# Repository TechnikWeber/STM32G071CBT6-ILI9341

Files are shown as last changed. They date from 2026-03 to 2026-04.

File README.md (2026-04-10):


</br>





Known issues:
ILI9341 Footprint doesnt match!



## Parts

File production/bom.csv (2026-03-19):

Designator | Footprint | Quantity | Value | LCSC Part #
C1, C2 | 0805 | 2 | 6.8pF
C10, C11, C5, C6, C8 | 0805 | 5 | 100nF
C12, C13 | CP_Radial_D6.3mm_P2.50mm | 2 | 10uF
C3, C4 | 0805 | 2 | 22pF
C7 | 0805 | 1 | 4.7uF
D2 | 0805 | 1 | Red
DS1 | ILI9341 | 1 | ILI9341
IC1 | QFP50P900X900X160-48N | 1 | STM32G071CBT6 | C432212
J4, J5 | PinHeader_1x03_P2.54mm_Vertical | 2 | Conn_01x03
R1 | 0805 | 1 | 150R
SW1 | SW_SPST_PTS645Sx43SMTR92 | 1 | RESET | C7470157
SW2 | SW_SPST_PTS645Sx43SMTR92 | 1 | BOOT0 | C7470157
SW3 | SW_SPST_PTS645Sx43SMTR92 | 1 | USER | C7470157
U1 | SOT-223-3_TabPin2 | 1 | AMS1117-3.3
Y1 | Crystal_SMD_3215-2Pin_3.2x1.5mm | 1 | 32.768kHz 6pF | C95361
Y2 | Crystal_SMD_HC49-SD | 1 | 16MHz 16pF | C19631568

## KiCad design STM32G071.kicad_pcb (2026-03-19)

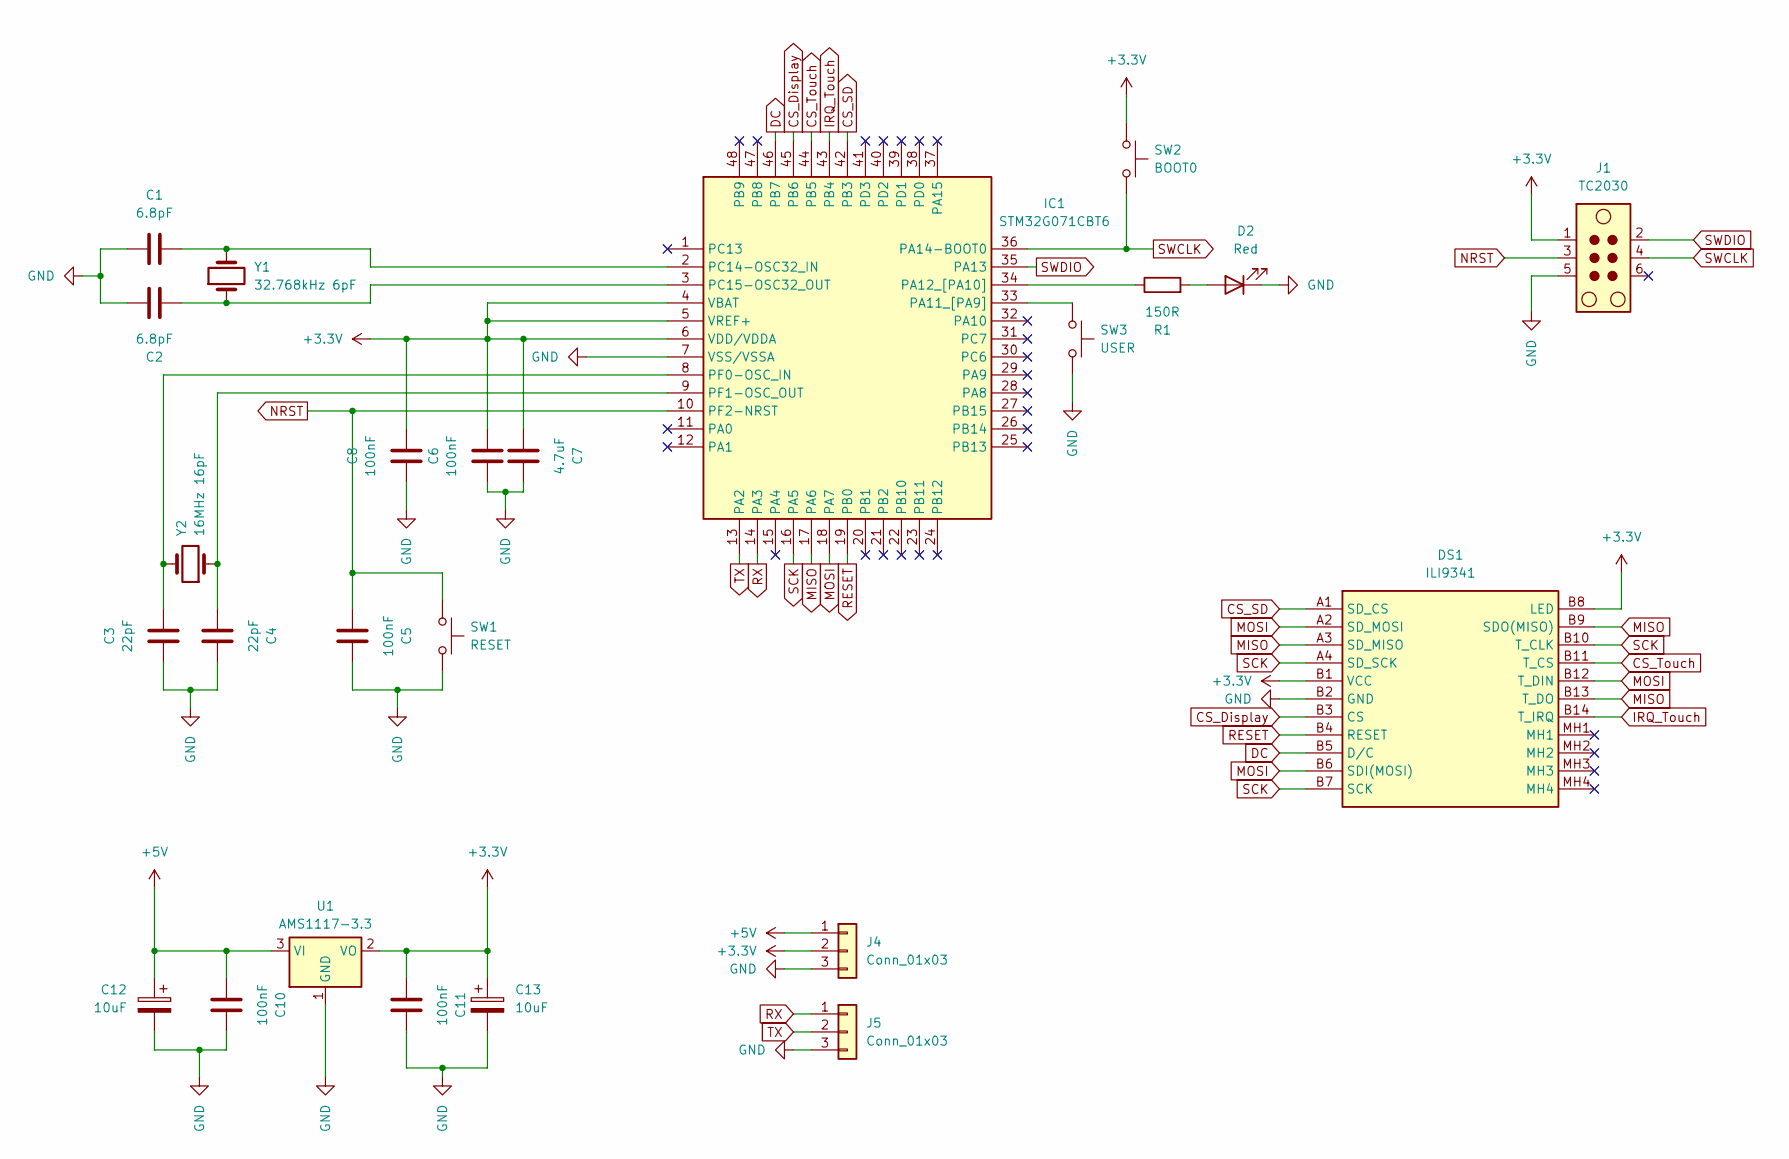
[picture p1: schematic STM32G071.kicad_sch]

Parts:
C1, C2: 6.8pF; C_0805_2012Metric; JLC C1832
C3: 22pF; C_0805_2012Metric; JLC C1804
C4: 22pF; C_0805_2012Metric
C5, C6, C8, C10, C11: 100nF; C_0805_2012Metric; JLC C49678
C7: 4.7uF; C_0805_2012Metric; JLC C1779
C12, C13: 10uF; CP_Radial_D6.3mm_P2.50mm
D2: Red; LED_0805_2012Metric
DS1: ILI9341; Manufacturer_Part_Number ILI9341
IC1: STM32G071CBT6; QFP50P900X900X160-48N; Manufacturer_Part_Number STM32G071CBT6; Mouser Part Number 511-STM32G071CBT6
J1: TC2030; Tag-Connect_TC2030-IDC-FP_2x03_P1.27mm_Vertical
J4, J5: Conn_01x03; PinHeader_1x03_P2.54mm_Vertical
R1: 150R; R_0805_2012Metric; JLC C17471
SW1: RESET; SW_SPST_PTS645Sx43SMTR92; JLC C7470157
SW2: BOOT0; SW_SPST_PTS645Sx43SMTR92; JLC C7470157
SW3: USER; SW_SPST_PTS645Sx43SMTR92; JLC C7470157
U1: AMS1117-3.3; SOT-223-3_TabPin2
Y1: 32.768kHz 6pF; Crystal_SMD_3215-2Pin_3.2x1.5mm; JLC C95361
Y2: 16MHz 16pF; Crystal_SMD_HC49-SD; JLC C19631568

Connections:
+3.3V: C6.2, C7.2, C8.2, C11.2, C13.1, DS1.B1 (VCC), DS1.B8 (LED), IC1.4 (VBAT), IC1.5 (VREF+), IC1.6 (VDD/VDDA), J1.1, J4.2, SW2.1, U1.2 (VO)
+5V: C10.2, C12.1, J4.1, U1.3 (VI)
CS_Display: DS1.B3 (CS), IC1.45 (PB6)
CS_SD: DS1.A1 (SD_CS), IC1.42 (PB3)
CS_Touch: DS1.B11 (T_CS), IC1.44 (PB5)
DC: DS1.B5 (D/C), IC1.46 (PB7)
GND: C1.1, C2.1, C3.1, C4.1, C5.1, C6.1, C7.1, C8.1, C10.1, C11.1, C12.2, C13.2, D2.1 (K), DS1.B2 (GND), IC1.7 (VSS/VSSA), J1.5, J4.3, J5.3, SW1.2, SW3.2, U1.1 (GND)
IRQ_Touch: DS1.B14 (T_IRQ), IC1.43 (PB4)
MISO: DS1.A3 (SD_MISO), DS1.B9 (SDO(MISO)), DS1.B13 (T_DO), IC1.17 (PA6)
MOSI: DS1.A2 (SD_MOSI), DS1.B6 (SDI(MOSI)), DS1.B12 (T_DIN), IC1.18 (PA7)
NRST: C5.2, IC1.10 (PF2-NRST), J1.3, SW1.1
unnamed: D2.2 (A), R1.2
unnamed: IC1.33 (PA11_[PA9]), SW3.1
unnamed: IC1.34 (PA12_[PA10]), R1.1
unnamed: C1.2, IC1.2 (PC14-OSC32_IN), Y1.2
unnamed: C2.2, IC1.3 (PC15-OSC32_OUT), Y1.1
unnamed: C3.2, IC1.8 (PF0-OSC_IN), Y2.2
unnamed: C4.2, IC1.9 (PF1-OSC_OUT), Y2.1
RESET: DS1.B4 (RESET), IC1.19 (PB0)
RX: IC1.14 (PA3), J5.1
SCK: DS1.A4 (SD_SCK), DS1.B7 (SCK), DS1.B10 (T_CLK), IC1.16 (PA5)
SWCLK: IC1.36 (PA14-BOOT0), J1.4, SW2.2
SWDIO: IC1.35 (PA13), J1.2
TX: IC1.13 (PA2), J5.2

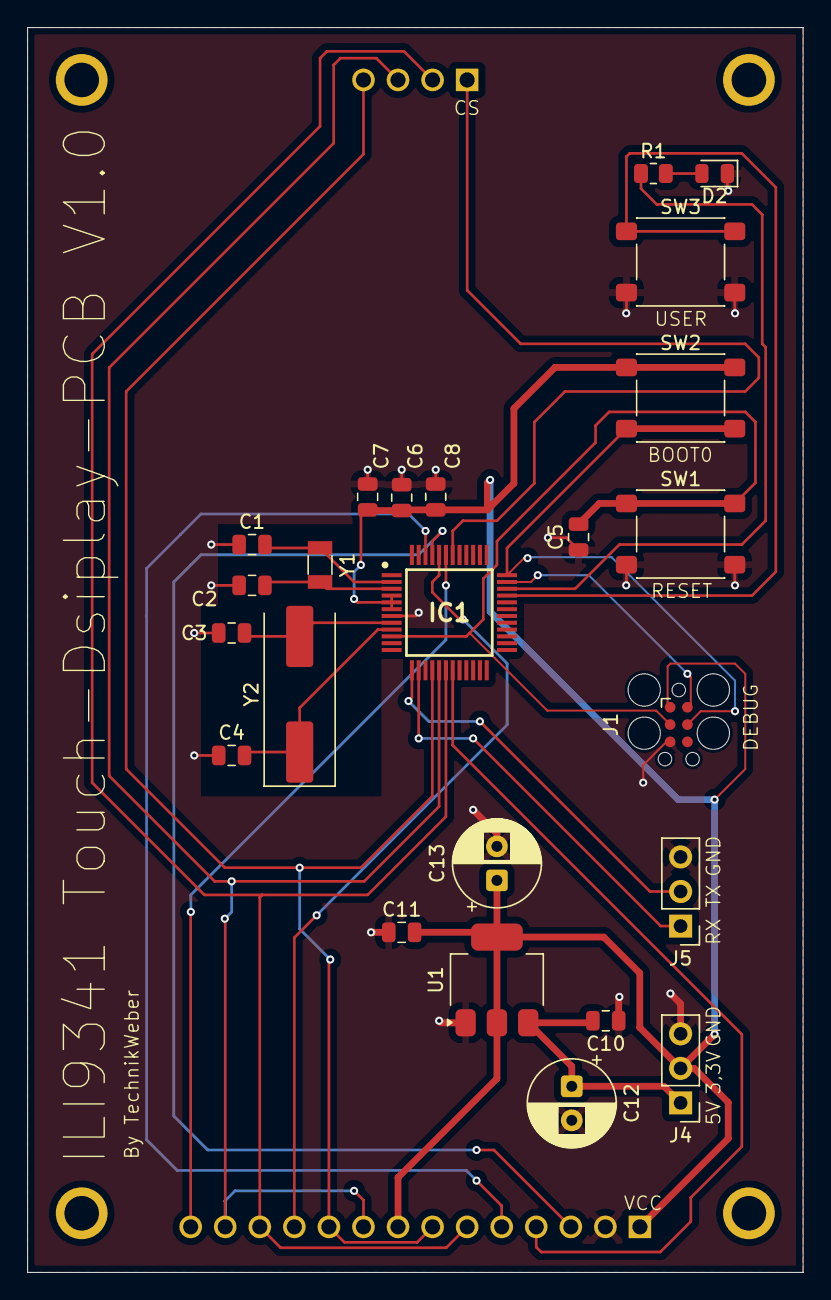
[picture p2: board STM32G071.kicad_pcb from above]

Board: 2 copper layers, 57.0 x 91.5 mm, 25 parts (1 on the bottom side), 24 nets.

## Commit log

2026-04-10 Add files via upload
    Display, touch, led and button is working.
2026-10-27 README with description and board render; drop KiCad backups
